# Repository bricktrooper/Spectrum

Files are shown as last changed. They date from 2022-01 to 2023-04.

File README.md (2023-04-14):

# Spectrum

Spectrum is a 10-band stereo graphic equalizer circuit.  It uses active band pass filters in a multiple feedback configuration.  Each band can be individually amplified or attenuated using linear potentiometers.  The circuit requires an external power source of at least 5 V at 250 mA.

## Background

### Graphic Equalizers

A graphic equalizer is a piece of audio equipment that isolates different ranges of frequencies from an audio signal.  These ranges can then be individually amplified (boosted) or attenuated (cut).  The modified signals are mixed back together into a single audio signal which appears at the output.  The resulting signal is the same audio but with each frequency range adjusted with a desired gain.

### Stereo Sound

The most basic form of electrical audio signals is "mono".  This is a single audio signal that plays through all the speakers.  "Stereo" uses two separate audio signals that differ slightly but can be used to give the perception of spatial audio.  Typically, the signals are used to drive separate "left" and "right" speakers.  A graphic equalizer only operates on a single mono signal.  Spectrum effectively uses two identical mono circuits to modify both channels of stereo audio.  The resulting output can be played through stereo headphones.  The circuit must be powered by an external wall adapter or any other 5 V source that can supply approximately 250 mA of current.

## Circuit Design

### Power Supply

Spectrum uses a 5 V power supply that is regulated by an L7805 LDO.  Traditionally, operational amplifiers use a bipolar supply of +VDD and -VDD, with the ground point of the signal being 0 V.  This is not possible with a single supply.  Therefore, Spectrum raises the ground point to a virtual ground of (VDD / 2), or 2.5 V.  The op amps are supplied by 5 V and sink to 0 V (GND).  This provides 2.5 V of signal swing, which is enough for driving headphones to a considerable volume.  To drive large speakers, a separate amplifier should be used.  Capacitive coupling is used to inject an AC audio signal into a 2.5 V bias and decouple the bias at the output headphone jack.

### Preamplifier

The preamplifier's job is to drive the rest of the circuit, effectively isolating the input resistance of the circuit from the audio source.  This is important because headphone jack outputs cannot drive very high impedances.  The preamplifer is also capable of amplifying or attenuating the input signal.  Amplification may be required if the input source is too quiet, while attenuation can be used to reduce distortion in the output signal.  The input to the preamplifier is further isolated using a 1:1 audio transformer.  This prevents the ground of the circuit from creating a ground loop through the audio cable, which creates an undesirable humming noise due to the oscillation of the AC mains voltage.  The preamplifier is implemented as a simple inverting amplifier.  A capacitor is used at the input to strip out any existing DC voltage and the output signal is re-biased at the virtual ground point.  A potentiometer is used in the feedback resistance to amplify or attenuate the signal linearly.

### Band Pass Filters

The core circuit of a graphic equalizer is the band pass filter, which isolates a range of frequencies.  Different resistor and capacitor values are used to achieve different cutoff frequencies over the bass, mid, and treble ranges.  Spectrum uses 10 filters for each audio channel.  The centre frequencies are chosen based on standard octaves:

- 31.5 Hz
- 63 Hz
- 125 Hz
- 250 Hz
- 500 Hz
- 1 kHz
- 2 kHz
- 4 kHz
- 8 kHz
- 16 kHz

These are active filters that used op amps in the multiple-feedback configuration, which allows the cutoff frequency to be changed without affecting the gain of the centre frequency.  The gain of all the filters have been adjusted so that the entire audio range has a flat gain response when the filter outputs are mixed back together.  Each individual filter has a DC gain of 1 V/V, with the exception of 31.5 Hz and 16 kHz, which have a gain of 1.6 V/V.  A quality factor of Q = 1.7 is used for all filters.  The component selection is as follows:

```
-------------------------------------------------------------------------------------------------------------------
| BAND    | ERROR      | C          | R1         | R2         | R3         | f          | Q          | A          |
-------------------------------------------------------------------------------------------------------------------
| 31.5 Hz | 0.816      | 0.33 uF    | 16 K       | 51 K       | 6.2 K      | 31.948 Hz  | 1.689      | 1.594 V/V  |
| 63 Hz   | 0.745      | 0.56 uF    | 7.5 K      | 15 K       | 1.6 K      | 63.902 Hz  | 1.686      | 1.000 V/V  |
| 125 Hz  | 0.709      | 0.22 uF    | 10 K       | 20 K       | 2 K        | 125.302 Hz | 1.732      | 1.000 V/V  |
| 250 Hz  | 0.709      | 0.1 uF     | 11 K       | 22 K       | 2.2 K      | 250.604 Hz | 1.732      | 1.000 V/V  |
| 500 Hz  | 1.204      | 0.1 uF     | 5.6 K      | 11 K       | 1.1 K      | 500.462 Hz | 1.729      | 0.982 V/V  |
| 1 kHz   | 1.328      | 0.18 uF    | 1.5 K      | 3 K        | 0.3 K      | 1.021 kHz  | 1.732      | 1.000 V/V  |
| 2 kHz   | 0.467      | 0.18 uF    | 0.75 K     | 1.5 K      | 0.16 K     | 1.988 kHz  | 1.686      | 1.000 V/V  |
| 4 kHz   | 1.078      | 0.068 uF   | 1 K        | 2 K        | 0.2 K      | 4.054 kHz  | 1.732      | 1.000 V/V  |
| 8 kHz   | 0.812      | 0.033 uF   | 1 K        | 2 K        | 0.22 K     | 8.031 kHz  | 1.665      | 1.000 V/V  |
| 16 kHz  | 0.916      | 0.022 uF   | 0.47 K     | 1.5 K      | 0.18 K     | 16.373 kHz | 1.697      | 1.596 V/V  |
-------------------------------------------------------------------------------------------------------------------
```

### Band Amplifiers

Each band pass filter is followed by an inverting amplifier, which has adjustable gain via a potentiometer in the feedback path.  This allows the user to individually boost or cut different frequency ranges.  At the potentiometer neutral point, the gain of the band amplifier is 0.5 V/V, meaning that each band can be attenuated down to 0 V/V or boosted up to 1 V/V, which is the gain of the band pass filters.  Any further amplification must be provided from the audio source and the preamplifier.  Due to band overlap, the actual realized gain is slightly higher or lower than in theory.  This is a tradeoff between selectivity and gain accuracy.

### Mixer

The mixer is a summing amplifier that re-combines all the band signals back into a single audio signal.  It has a fixed gain of 5 V/V, and the output signal can directly drive low-impedance headphones.  The output signal runs through a large capacitor to cut out the virtual ground DC bias to avoid damaging the headphone speaker coils.  This turns the signal into an AC waveform with a GND as the reference point.

## Schematic

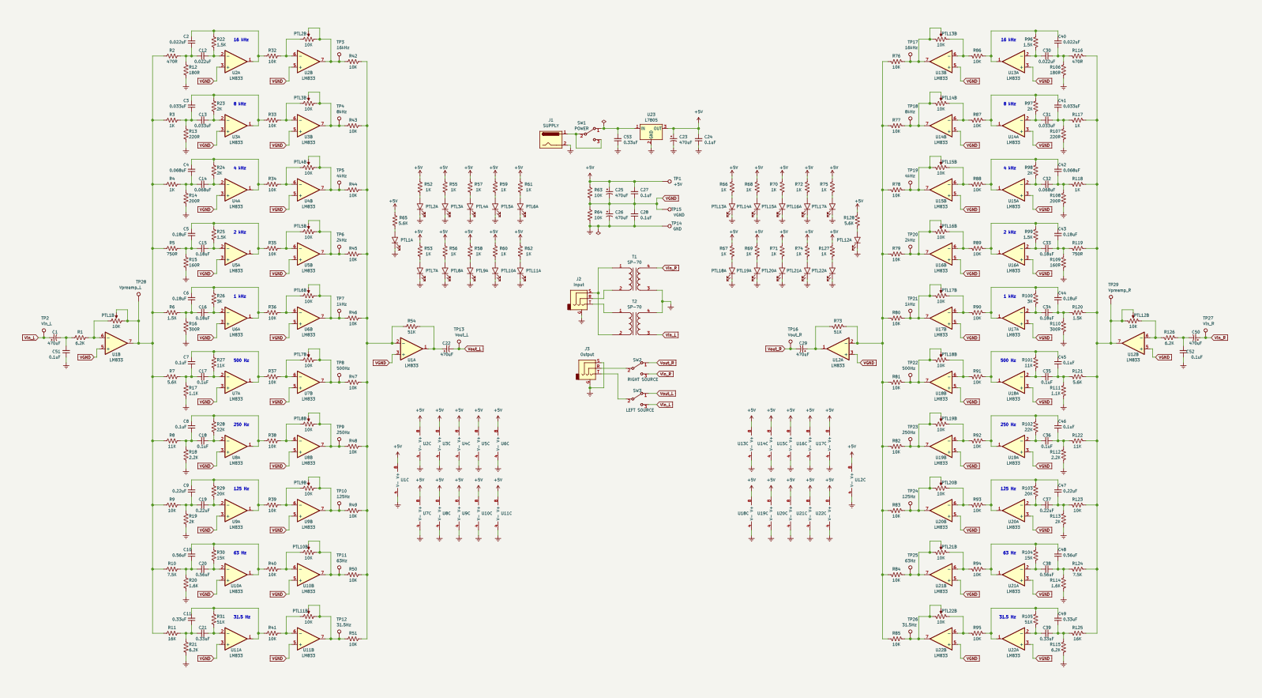
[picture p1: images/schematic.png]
Schematic


## Circuit Board

### Top
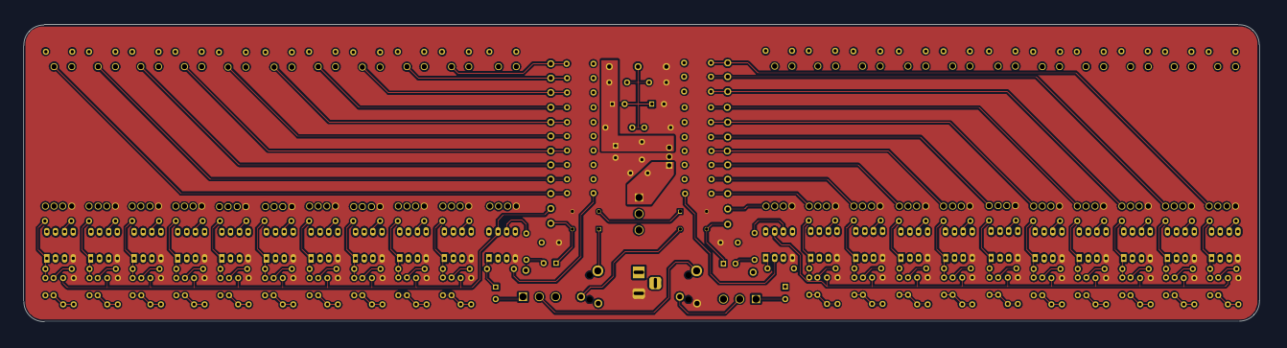
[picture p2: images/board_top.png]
Top


### Bottom
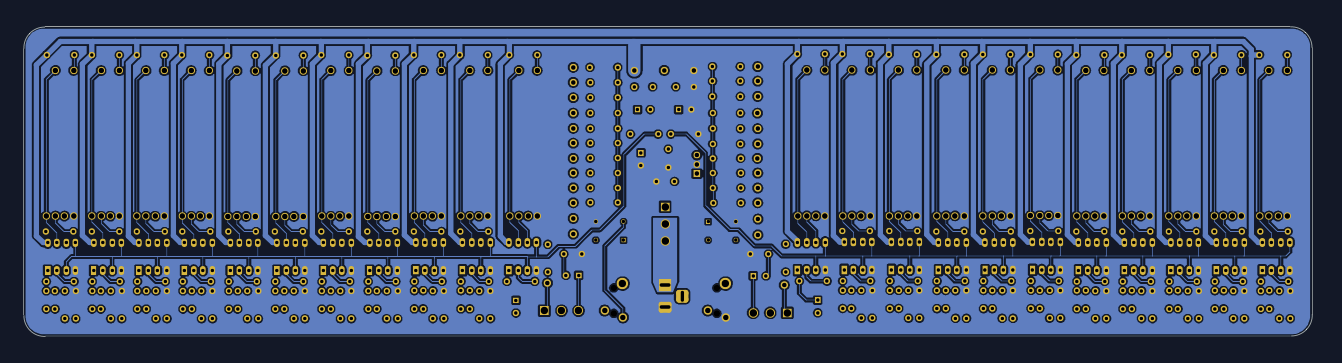
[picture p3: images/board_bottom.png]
Bottom


### Assembled
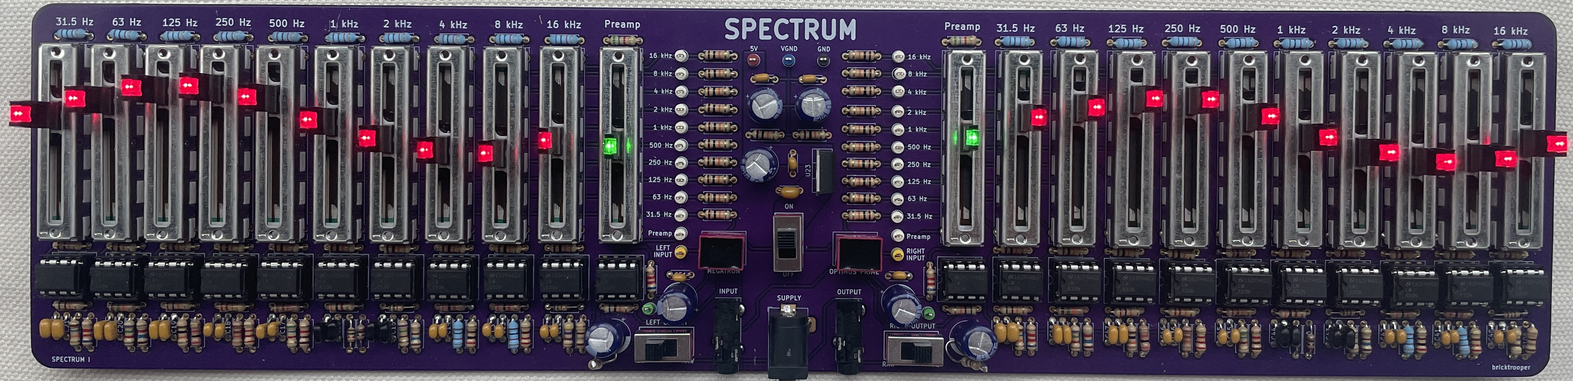
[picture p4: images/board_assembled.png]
Assembled


## Revisions

- A 470R resistor was added to the audio output to mitigate the amplified hissing noise.  The side effect of this is reduced gain from the preamp and increased distortion in the output signal.

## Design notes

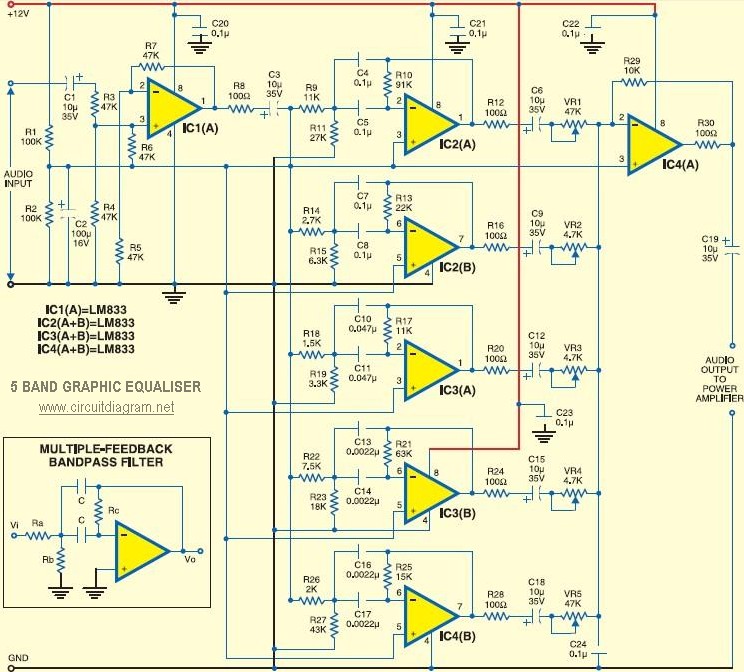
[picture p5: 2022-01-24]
resources/Single Supply Graphic EQ.jpg

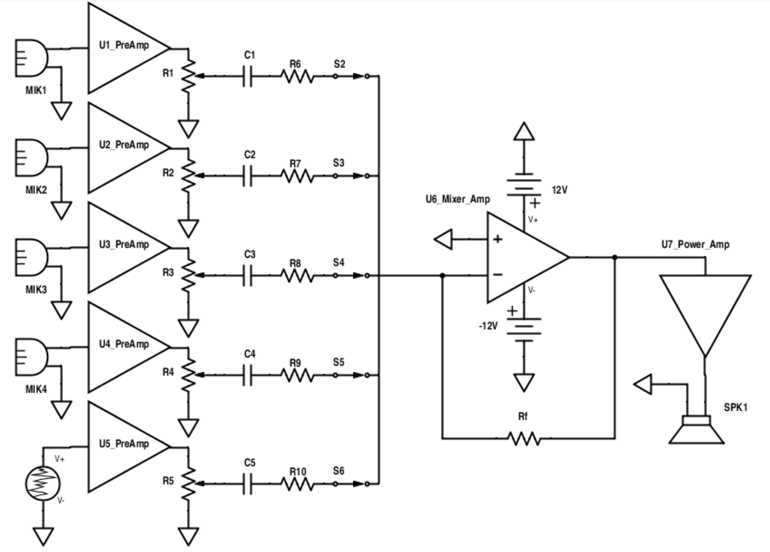
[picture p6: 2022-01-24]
resources/Summing Amplifier Audio Mixer 2.png

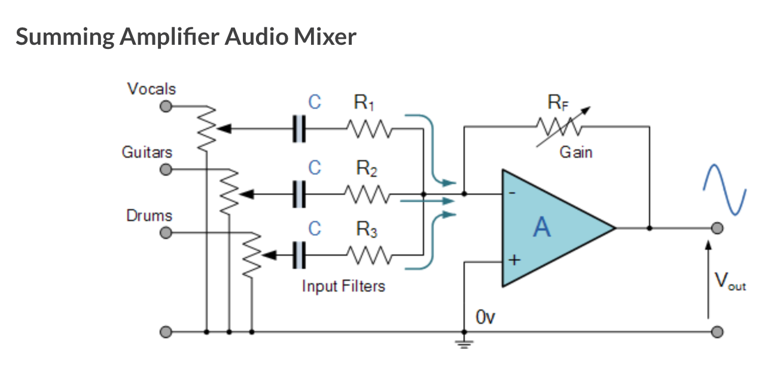
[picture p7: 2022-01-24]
resources/Summing Amplifier Audio Mixer 1.png

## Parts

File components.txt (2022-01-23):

Q = 1.7
A = 1 except for 31.5 Hz and 16 kHz which are 1.6

-------------------------------------------------------------------------------------------------------------------
| BAND    | ERROR      | C          | R1         | R2         | R3         | f          | Q          | A          |
-------------------------------------------------------------------------------------------------------------------
| 31.5 Hz | 0.816      | 0.33 uF    | 16 K       | 51 K       | 6.2 K      | 31.948 Hz  | 1.689      | 1.594 V/V  |
| 63 Hz   | 0.745      | 0.56 uF    | 7.5 K      | 15 K       | 1.6 K      | 63.902 Hz  | 1.686      | 1.000 V/V  |
| 125 Hz  | 0.709      | 0.22 uF    | 10 K       | 20 K       | 2 K        | 125.302 Hz | 1.732      | 1.000 V/V  |
| 250 Hz  | 0.709      | 0.1 uF     | 11 K       | 22 K       | 2.2 K      | 250.604 Hz | 1.732      | 1.000 V/V  |
| 500 Hz  | 1.204      | 0.1 uF     | 5.6 K      | 11 K       | 1.1 K      | 500.462 Hz | 1.729      | 0.982 V/V  |
| 1 kHz   | 1.328      | 0.18 uF    | 1.5 K      | 3 K        | 0.3 K      | 1.021 kHz  | 1.732      | 1.000 V/V  |
| 2 kHz   | 0.467      | 0.18 uF    | 0.75 K     | 1.5 K      | 0.16 K     | 1.988 kHz  | 1.686      | 1.000 V/V  |
| 4 kHz   | 1.078      | 0.068 uF   | 1 K        | 2 K        | 0.2 K      | 4.054 kHz  | 1.732      | 1.000 V/V  |
| 8 kHz   | 0.812      | 0.033 uF   | 1 K        | 2 K        | 0.22 K     | 8.031 kHz  | 1.665      | 1.000 V/V  |
| 16 kHz  | 0.916      | 0.022 uF   | 0.47 K     | 1.5 K      | 0.18 K     | 16.373 kHz | 1.697      | 1.596 V/V  |
-------------------------------------------------------------------------------------------------------------------

Blocking capacitors will be 10 uF each with a companion resistor of 100 R.
The POT will be 10 K (at least 10 times the size of the resistor).

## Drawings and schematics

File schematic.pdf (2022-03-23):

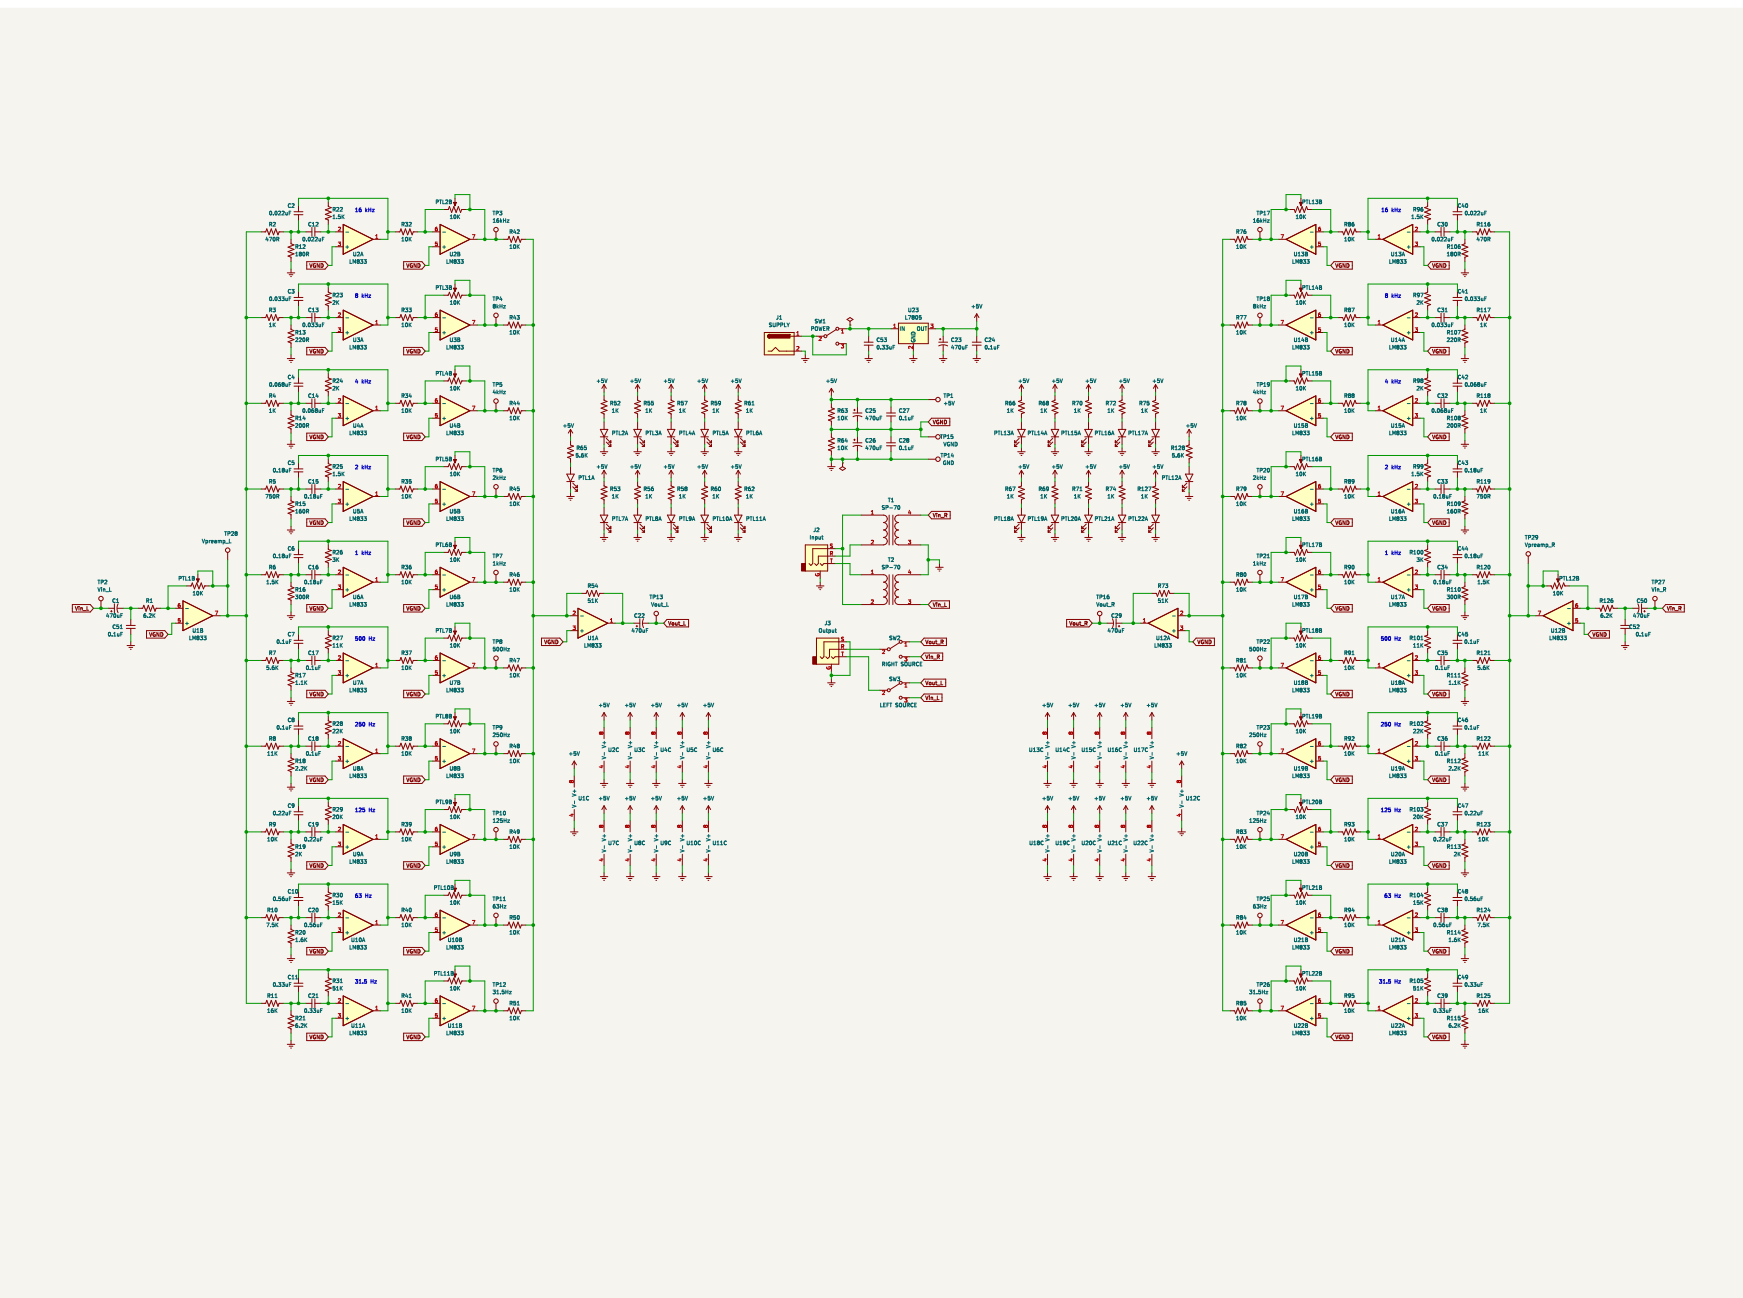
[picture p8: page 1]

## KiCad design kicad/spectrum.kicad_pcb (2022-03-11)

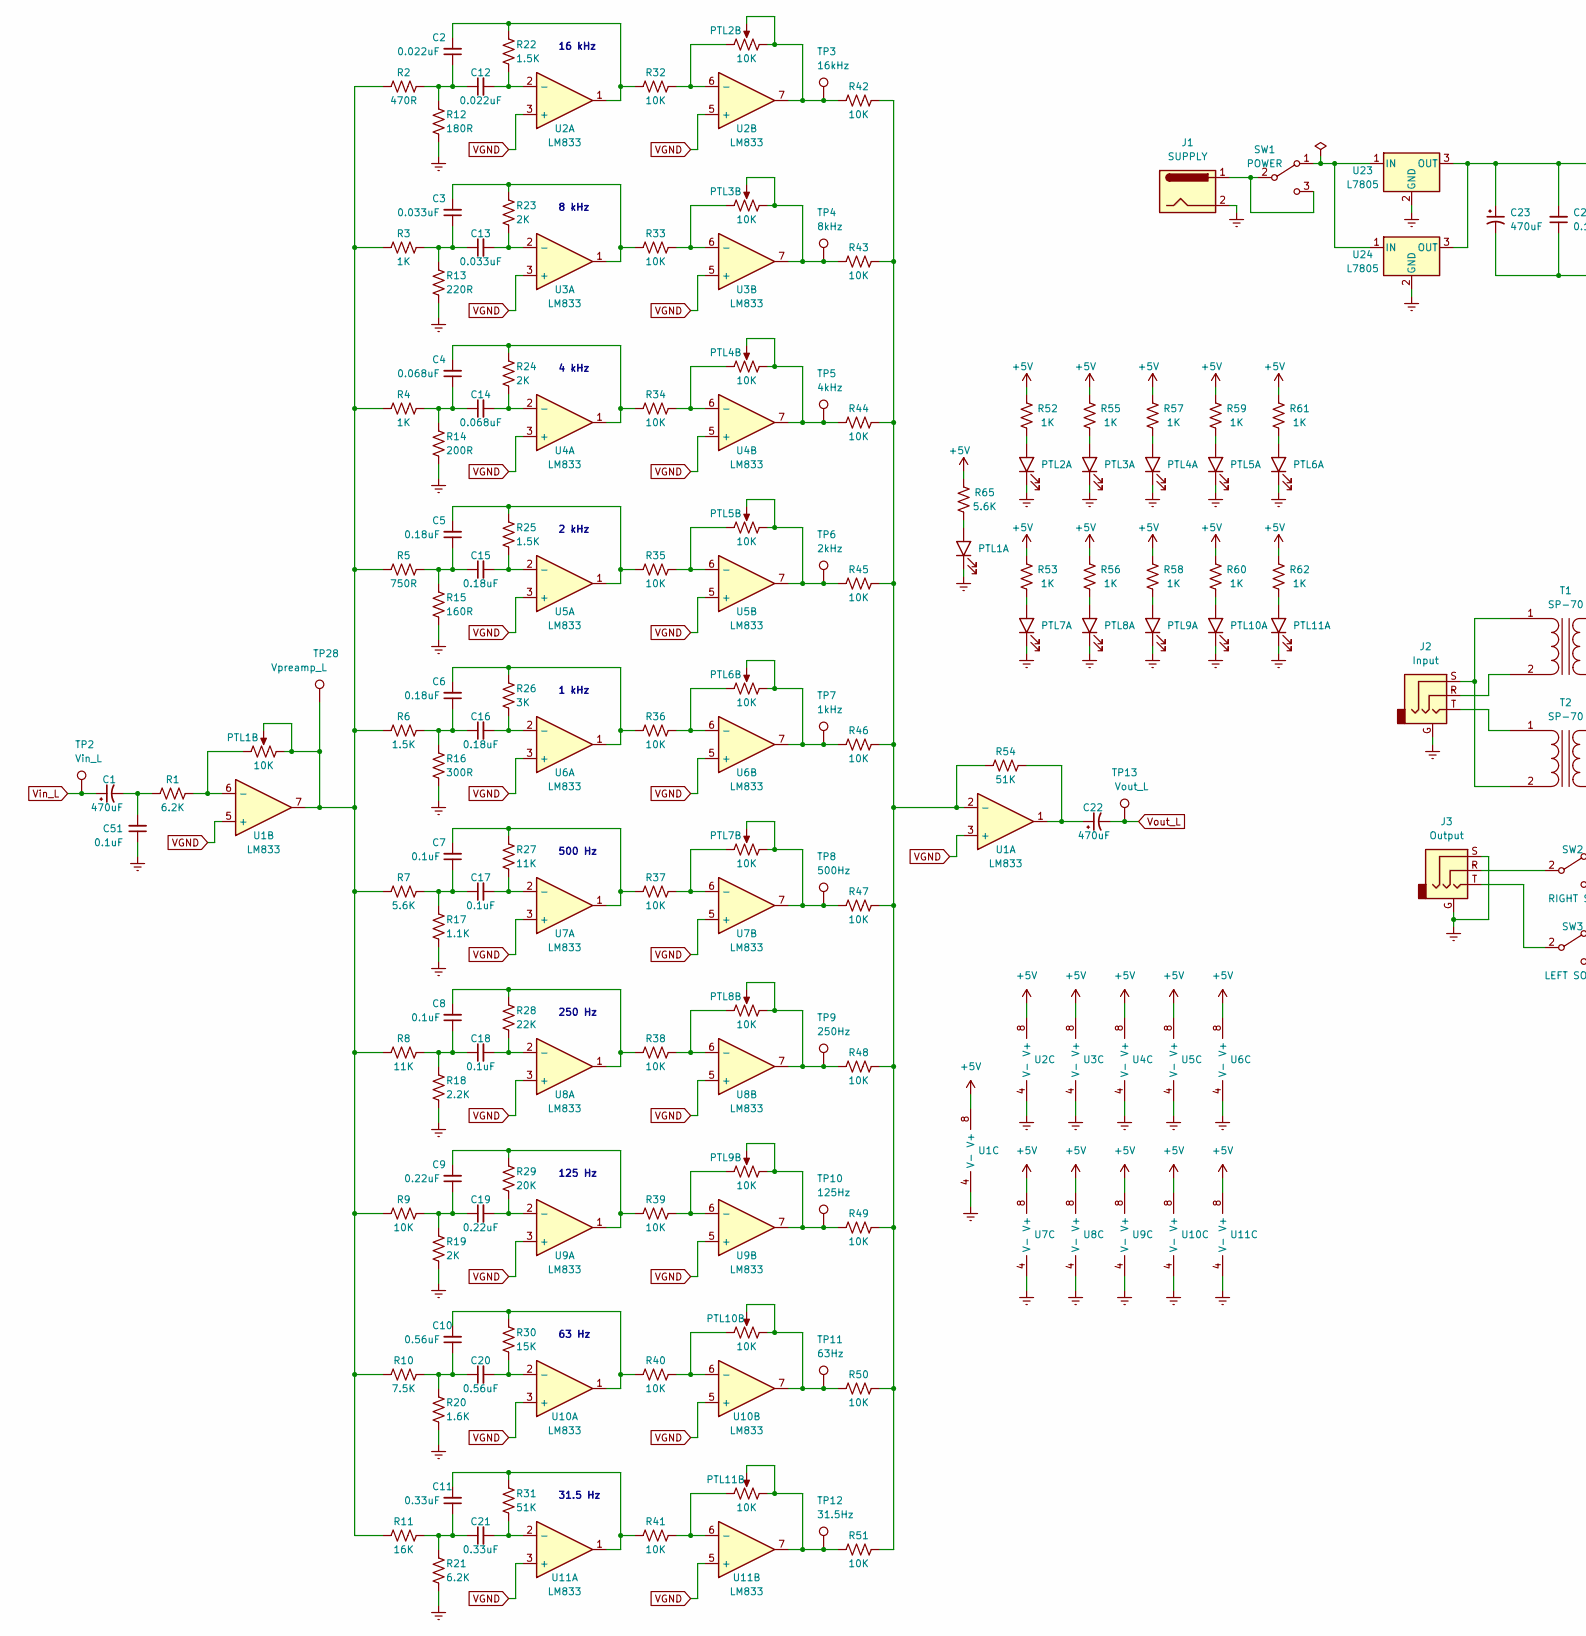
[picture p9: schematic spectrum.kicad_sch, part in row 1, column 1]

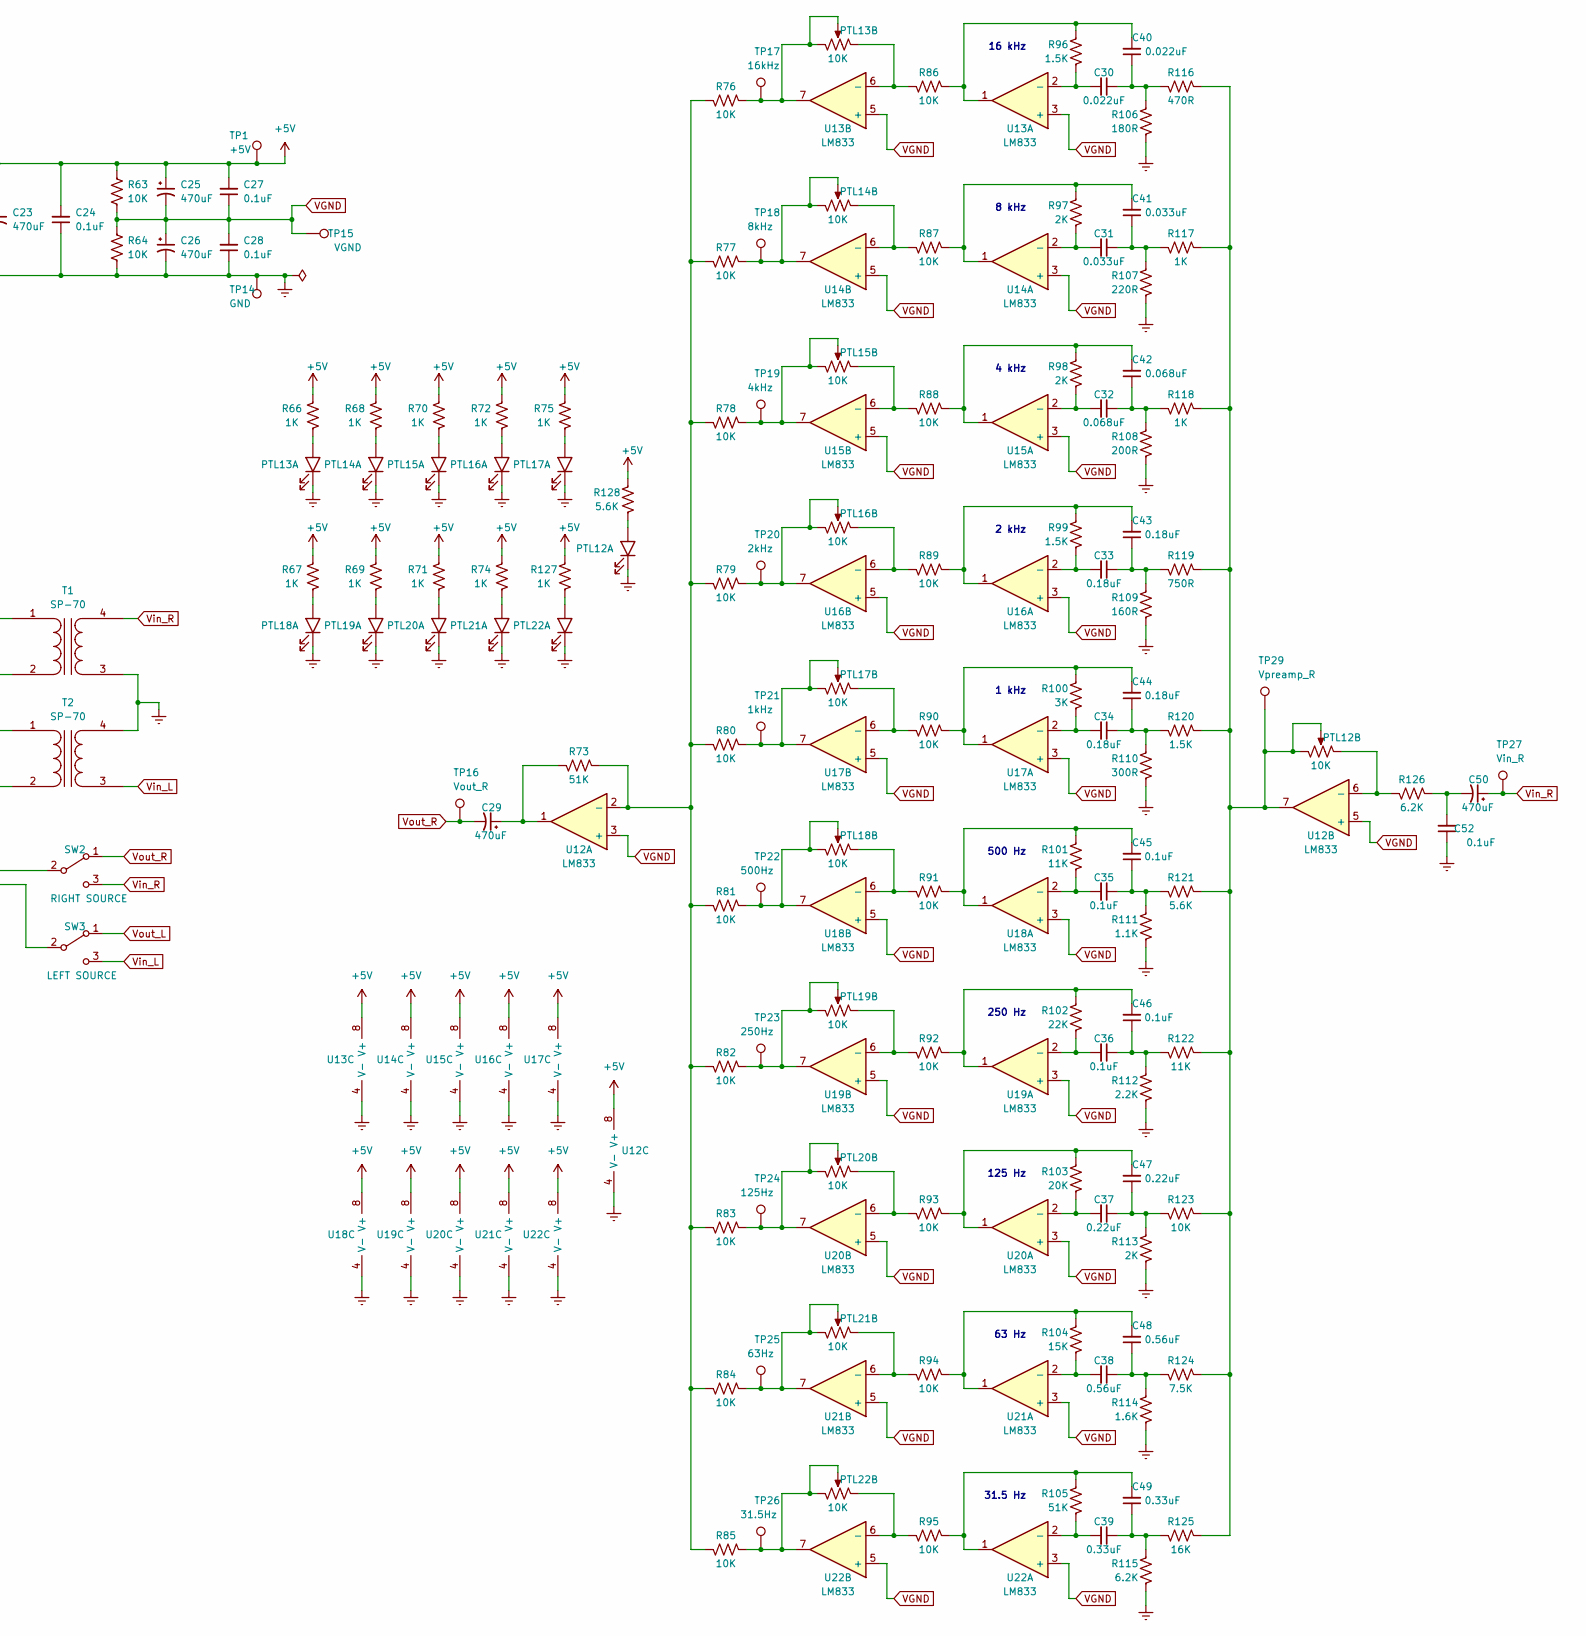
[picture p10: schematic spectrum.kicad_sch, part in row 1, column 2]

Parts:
C1, C22, C23, C25, C26, C29, C50: 470uF; CP_Radial_D8.0mm_P3.50mm
C2, C12, C30, C40: 0.022uF; C_Disc_D4.3mm_W1.9mm_P5.00mm
C3, C13, C31, C41: 0.033uF; C_Disc_D4.3mm_W1.9mm_P5.00mm
C4, C14, C32, C42: 0.068uF; C_Disc_D4.3mm_W1.9mm_P5.00mm
C5, C6, C15, C16, C33, C34, C43, C44: 0.18uF; C_Disc_D4.3mm_W1.9mm_P5.00mm
C7, C8, C17, C18, C24, C27, C28, C35, C36, C45, C46, C51, C52: 0.1uF; C_Disc_D4.3mm_W1.9mm_P5.00mm
C9, C19, C37, C47: 0.22uF; C_Disc_D4.3mm_W1.9mm_P5.00mm
C10, C20, C38, C48: 0.56uF; C_Disc_D4.3mm_W1.9mm_P5.00mm
C11, C21, C39, C49: 0.33uF; C_Disc_D4.3mm_W1.9mm_P5.00mm
J1: SUPPLY; BarrelJack_Horizontal
J2: Input; STX35013N
J3: Output; STX35013N
PTL1, PTL2, PTL3, PTL4, PTL5, PTL6, PTL7, PTL8, PTL9, PTL10, PTL11, PTL12, PTL13, PTL14, PTL15, PTL16, PTL17, PTL18, PTL19, PTL20, PTL21, PTL22: 10K; PTL30
R1, R21, R115, R126: 6.2K; R_Axial_DIN0207_L6.3mm_D2.5mm_P7.62mm_Horizontal
R2, R116: 470R; R_Axial_DIN0207_L6.3mm_D2.5mm_P7.62mm_Horizontal
R3, R4, R52, R53, R55, R56, R57, R58, R59, R60, R61, R62, R66, R67, R68, R69, R70, R71, R72, R74, R75, R117, R118, R127: 1K; R_Axial_DIN0207_L6.3mm_D2.5mm_P7.62mm_Horizontal
R5, R119: 750R; R_Axial_DIN0207_L6.3mm_D2.5mm_P7.62mm_Horizontal
R6, R22, R25, R96, R99, R120: 1.5K; R_Axial_DIN0207_L6.3mm_D2.5mm_P7.62mm_Horizontal
R7, R65, R121, R128: 5.6K; R_Axial_DIN0207_L6.3mm_D2.5mm_P7.62mm_Horizontal
R8, R27, R101, R122: 11K; R_Axial_DIN0207_L6.3mm_D2.5mm_P7.62mm_Horizontal
R9, R32, R33, R34, R35, R36, R37, R38, R39, R40, R41, R42, R43, R44, R45, R46, R47, R48, R49, R50, R51, R63, R64, R76, R77, R78, R79, R80, R81, R82, R83, R84, R85, R86, R87, R88, R89, R90, R91, R92, R93, R94, R95, R123: 10K; R_Axial_DIN0207_L6.3mm_D2.5mm_P7.62mm_Horizontal
R10, R124: 7.5K; R_Axial_DIN0207_L6.3mm_D2.5mm_P7.62mm_Horizontal
R11, R125: 16K; R_Axial_DIN0207_L6.3mm_D2.5mm_P7.62mm_Horizontal
R12, R106: 180R; R_Axial_DIN0207_L6.3mm_D2.5mm_P7.62mm_Horizontal
R13, R107: 220R; R_Axial_DIN0207_L6.3mm_D2.5mm_P7.62mm_Horizontal
R14, R108: 200R; R_Axial_DIN0207_L6.3mm_D2.5mm_P7.62mm_Horizontal
R15, R109: 160R; R_Axial_DIN0207_L6.3mm_D2.5mm_P7.62mm_Horizontal
R16, R110: 300R; R_Axial_DIN0207_L6.3mm_D2.5mm_P7.62mm_Horizontal
R17, R111: 1.1K; R_Axial_DIN0207_L6.3mm_D2.5mm_P7.62mm_Horizontal
R18, R112: 2.2K; R_Axial_DIN0207_L6.3mm_D2.5mm_P7.62mm_Horizontal
R19, R23, R24, R97, R98, R113: 2K; R_Axial_DIN0207_L6.3mm_D2.5mm_P7.62mm_Horizontal
R20, R114: 1.6K; R_Axial_DIN0207_L6.3mm_D2.5mm_P7.62mm_Horizontal
R26, R100: 3K; R_Axial_DIN0207_L6.3mm_D2.5mm_P7.62mm_Horizontal
R28, R102: 22K; R_Axial_DIN0207_L6.3mm_D2.5mm_P7.62mm_Horizontal
R29, R103: 20K; R_Axial_DIN0207_L6.3mm_D2.5mm_P7.62mm_Horizontal
R30, R104: 15K; R_Axial_DIN0207_L6.3mm_D2.5mm_P7.62mm_Horizontal
R31, R54, R73, R105: 51K; R_Axial_DIN0207_L6.3mm_D2.5mm_P7.62mm_Horizontal
SW1: POWER; SW_1101M2S3CQE2
SW2: RIGHT SOURCE; SW_1101M2S3CQE2
SW3: LEFT SOURCE; SW_1101M2S3CQE2
T1, T2: SP-70; SP70
TP1: +5V; TestPoint_Keystone_5000-5004_Miniature
TP2: Vin_L; TestPoint_Keystone_5000-5004_Miniature
TP3, TP17: 16kHz; TestPoint_Keystone_5000-5004_Miniature
TP4, TP18: 8kHz; TestPoint_Keystone_5000-5004_Miniature
TP5, TP19: 4kHz; TestPoint_Keystone_5000-5004_Miniature
TP6, TP20: 2kHz; TestPoint_Keystone_5000-5004_Miniature
TP7, TP21: 1kHz; TestPoint_Keystone_5000-5004_Miniature
TP8, TP22: 500Hz; TestPoint_Keystone_5000-5004_Miniature
TP9, TP23: 250Hz; TestPoint_Keystone_5000-5004_Miniature
TP10, TP24: 125Hz; TestPoint_Keystone_5000-5004_Miniature
TP11, TP25: 63Hz; TestPoint_Keystone_5000-5004_Miniature
TP12, TP26: 31.5Hz; TestPoint_Keystone_5000-5004_Miniature
TP13: Vout_L; TestPoint_Keystone_5000-5004_Miniature
TP14: GND; TestPoint_Keystone_5000-5004_Miniature
TP15: VGND; TestPoint_Keystone_5000-5004_Miniature
TP16: Vout_R; TestPoint_Keystone_5000-5004_Miniature
TP27: Vin_R; TestPoint_Keystone_5000-5004_Miniature
TP28: Vpreamp_L; TestPoint_Keystone_5000-5004_Miniature
TP29: Vpreamp_R; TestPoint_Keystone_5000-5004_Miniature
U1, U2, U3, U4, U5, U6, U7, U8, U9, U10, U11, U12, U13, U14, U15, U16, U17, U18, U19, U20, U21, U22: LM833; DIP-8_W7.62mm_Socket_LongPads
U23, U24: L7805; TO-220-3_Vertical

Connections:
+5V: C23.1, C24.2, C25.1, C27.2, R52.1, R53.1, R55.1, R56.1, R57.1, R58.1, R59.1, R60.1, R61.1, R62.1, R63.1, R65.1, R66.1, R67.1, R68.1, R69.1, R70.1, R71.1, R72.1, R74.1, R75.1, R127.1, R128.1, TP1.1, U1.8 (V+), U2.8 (V+), U3.8 (V+), U4.8 (V+), U5.8 (V+), U6.8 (V+), U7.8 (V+), U8.8 (V+), U9.8 (V+), U10.8 (V+), U11.8 (V+), U12.8 (V+), U13.8 (V+), U14.8 (V+), U15.8 (V+), U16.8 (V+), U17.8 (V+), U18.8 (V+), U19.8 (V+), U20.8 (V+), U21.8 (V+), U22.8 (V+), U23.3 (OUT), U24.3 (OUT)
GNDREF: C23.2, C24.1, C26.2, C28.1, C51.1, C52.1, J1.2, J2.G, J3.G, J3.S, PTL1.5 (E), PTL2.5 (E), PTL3.5 (E), PTL4.5 (E), PTL5.5 (E), PTL6.5 (E), PTL7.5 (E), PTL8.5 (E), PTL9.5 (E), PTL10.5 (E), PTL11.5 (E), PTL12.5 (E), PTL13.5 (E), PTL14.5 (E), PTL15.5 (E), PTL16.5 (E), PTL17.5 (E), PTL18.5 (E), PTL19.5 (E), PTL20.5 (E), PTL21.5 (E), PTL22.5 (E), R12.2, R13.2, R14.2, R15.2, R16.2, R17.2, R18.2, R19.2, R20.2, R21.2, R64.2, R106.2, R107.2, R108.2, R109.2, R110.2, R111.2, R112.2, R113.2, R114.2, R115.2, T1.3 (SA), T2.4 (SB), TP14.1, U1.4 (V-), U2.4 (V-), U3.4 (V-), U4.4 (V-), U5.4 (V-), U6.4 (V-), U7.4 (V-), U8.4 (V-), U9.4 (V-), U10.4 (V-), U11.4 (V-), U12.4 (V-), U13.4 (V-), U14.4 (V-), U15.4 (V-), U16.4 (V-), U17.4 (V-), U18.4 (V-), U19.4 (V-), U20.4 (V-), U21.4 (V-), U22.4 (V-), U23.2 (GND), U24.2 (GND)
unnamed: C1.2, C51.2, R1.2
unnamed: C2.2, R22.1, R32.2, U2.1
unnamed: C3.2, R23.1, R33.2, U3.1
unnamed: C4.2, R24.1, R34.2, U4.1
unnamed: C5.2, R25.1, R35.2, U5.1
unnamed: C6.2, R26.1, R36.2, U6.1
unnamed: C7.2, R27.1, R37.2, U7.1
unnamed: C8.2, R28.1, R38.2, U8.1
unnamed: C9.2, R29.1, R39.2, U9.1
unnamed: C10.1, C20.1, R10.1, R20.1
unnamed: C10.2, R30.1, R40.2, U10.1
unnamed: C11.1, C21.1, R11.1, R21.1
unnamed: C11.2, R31.1, R41.2, U11.1
unnamed: C2.1, C12.1, R2.1, R12.1
unnamed: C12.2, R22.2, U2.2 (-)
unnamed: C3.1, C13.1, R3.1, R13.1
unnamed: C13.2, R23.2, U3.2 (-)
unnamed: C4.1, C14.1, R4.1, R14.1
unnamed: C14.2, R24.2, U4.2 (-)
unnamed: C5.1, C15.1, R5.1, R15.1
unnamed: C15.2, R25.2, U5.2 (-)
unnamed: C6.1, C16.1, R6.1, R16.1
unnamed: C16.2, R26.2, U6.2 (-)
unnamed: C7.1, C17.1, R7.1, R17.1
unnamed: C17.2, R27.2, U7.2 (-)
unnamed: C8.1, C18.1, R8.1, R18.1
unnamed: C18.2, R28.2, U8.2 (-)
unnamed: C9.1, C19.1, R9.1, R19.1
unnamed: C19.2, R29.2, U9.2 (-)
unnamed: C20.2, R30.2, U10.2 (-)
unnamed: C21.2, R31.2, U11.2 (-)
unnamed: C22.1, R54.1, U1.1
unnamed: C29.1, R73.1, U12.1
unnamed: C30.1, C40.1, R106.1, R116.1
unnamed: C30.2, R96.2, U13.2 (-)
unnamed: C31.1, C41.1, R107.1, R117.1
unnamed: C31.2, R97.2, U14.2 (-)
unnamed: C32.1, C42.1, R108.1, R118.1
unnamed: C32.2, R98.2, U15.2 (-)
unnamed: C33.1, C43.1, R109.1, R119.1
unnamed: C33.2, R99.2, U16.2 (-)
unnamed: C34.1, C44.1, R110.1, R120.1
unnamed: C34.2, R100.2, U17.2 (-)
unnamed: C35.1, C45.1, R111.1, R121.1
unnamed: C35.2, R101.2, U18.2 (-)
unnamed: C36.1, C46.1, R112.1, R122.1
unnamed: C36.2, R102.2, U19.2 (-)
unnamed: C37.1, C47.1, R113.1, R123.1
unnamed: C37.2, R103.2, U20.2 (-)
unnamed: C38.1, C48.1, R114.1, R124.1
unnamed: C38.2, R104.2, U21.2 (-)
unnamed: C39.1, C49.1, R115.1, R125.1
unnamed: C39.2, R105.2, U22.2 (-)
unnamed: C40.2, R86.2, R96.1, U13.1
unnamed: C41.2, R87.2, R97.1, U14.1
unnamed: C42.2, R88.2, R98.1, U15.1
unnamed: C43.2, R89.2, R99.1, U16.1
unnamed: C44.2, R90.2, R100.1, U17.1
unnamed: C45.2, R91.2, R101.1, U18.1
unnamed: C46.2, R92.2, R102.1, U19.1
unnamed: C47.2, R93.2, R103.1, U20.1
unnamed: C48.2, R94.2, R104.1, U21.1
unnamed: C49.2, R95.2, R105.1, U22.1
unnamed: C50.2, C52.2, R126.2
unnamed: J1.1, SW1.2 (B), SW1.3 (C)
unnamed: J2.R, T1.2 (AB)
unnamed: J2.S, T1.1 (AA), T2.2 (AB)
unnamed: J2.T, T2.1 (AA)
unnamed: J3.R, SW2.2 (B)
unnamed: J3.T, SW3.2 (B)
unnamed: PTL1.1, R1.1, U1.6 (-)
unnamed: PTL1.2, PTL1.3, R2.2, R3.2, R4.2, R5.2, R6.2, R7.2, R8.2, R9.2, R10.2, R11.2, TP28.1, U1.7
unnamed: PTL1.4 (B), R65.2
unnamed: PTL2.1, R32.1, U2.6 (-)
unnamed: PTL2.2, PTL2.3, R42.2, TP3.1, U2.7
unnamed: PTL2.4 (B), R52.2
unnamed: PTL3.1, R33.1, U3.6 (-)
unnamed: PTL3.2, PTL3.3, R43.2, TP4.1, U3.7
unnamed: PTL3.4 (B), R55.2
unnamed: PTL4.1, R34.1, U4.6 (-)
unnamed: PTL4.2, PTL4.3, R44.2, TP5.1, U4.7
unnamed: PTL4.4 (B), R57.2
unnamed: PTL5.1, R35.1, U5.6 (-)
unnamed: PTL5.2, PTL5.3, R45.2, TP6.1, U5.7
unnamed: PTL5.4 (B), R59.2
unnamed: PTL6.1, R36.1, U6.6 (-)
unnamed: PTL6.2, PTL6.3, R46.2, TP7.1, U6.7
unnamed: PTL6.4 (B), R61.2
unnamed: PTL7.1, R37.1, U7.6 (-)
unnamed: PTL7.2, PTL7.3, R47.2, TP8.1, U7.7
unnamed: PTL7.4 (B), R53.2
unnamed: PTL8.1, R38.1, U8.6 (-)
unnamed: PTL8.2, PTL8.3, R48.2, TP9.1, U8.7
unnamed: PTL8.4 (B), R56.2
unnamed: PTL9.1, R39.1, U9.6 (-)
unnamed: PTL9.2, PTL9.3, R49.2, TP10.1, U9.7
unnamed: PTL9.4 (B), R58.2
unnamed: PTL10.1, R40.1, U10.6 (-)
unnamed: PTL10.2, PTL10.3, R50.2, TP11.1, U10.7
unnamed: PTL10.4 (B), R60.2
unnamed: PTL11.1, R41.1, U11.6 (-)
unnamed: PTL11.2, PTL11.3, R51.2, TP12.1, U11.7
unnamed: PTL11.4 (B), R62.2
unnamed: PTL12.1, R126.1, U12.6 (-)
unnamed: PTL12.2, PTL12.3, R116.2, R117.2, R118.2, R119.2, R120.2, R121.2, R122.2, R123.2, R124.2, R125.2, TP29.1, U12.7
unnamed: PTL12.4 (B), R128.2
unnamed: PTL13.1, R86.1, U13.6 (-)
unnamed: PTL13.2, PTL13.3, R76.2, TP17.1, U13.7
unnamed: PTL13.4 (B), R66.2
unnamed: PTL14.1, R87.1, U14.6 (-)
unnamed: PTL14.2, PTL14.3, R77.2, TP18.1, U14.7
unnamed: PTL14.4 (B), R68.2
unnamed: PTL15.1, R88.1, U15.6 (-)
unnamed: PTL15.2, PTL15.3, R78.2, TP19.1, U15.7
unnamed: PTL15.4 (B), R70.2
unnamed: PTL16.1, R89.1, U16.6 (-)
unnamed: PTL16.2, PTL16.3, R79.2, TP20.1, U16.7
unnamed: PTL16.4 (B), R72.2
unnamed: PTL17.1, R90.1, U17.6 (-)
unnamed: PTL17.2, PTL17.3, R80.2, TP21.1, U17.7
unnamed: PTL17.4 (B), R75.2
unnamed: PTL18.1, R91.1, U18.6 (-)
unnamed: PTL18.2, PTL18.3, R81.2, TP22.1, U18.7
unnamed: PTL18.4 (B), R67.2
unnamed: PTL19.1, R92.1, U19.6 (-)
unnamed: PTL19.2, PTL19.3, R82.2, TP23.1, U19.7
unnamed: PTL19.4 (B), R69.2
unnamed: PTL20.1, R93.1, U20.6 (-)
unnamed: PTL20.2, PTL20.3, R83.2, TP24.1, U20.7
unnamed: PTL20.4 (B), R71.2
unnamed: PTL21.1, R94.1, U21.6 (-)
unnamed: PTL21.2, PTL21.3, R84.2, TP25.1, U21.7
unnamed: PTL21.4 (B), R74.2
unnamed: PTL22.1, R95.1, U22.6 (-)
unnamed: PTL22.2, PTL22.3, R85.2, TP26.1, U22.7
unnamed: PTL22.4 (B), R127.2
unnamed: R42.1, R43.1, R44.1, R45.1, R46.1, R47.1, R48.1, R49.1, R50.1, R51.1, R54.2, U1.2 (-)
unnamed: R73.2, R76.1, R77.1, R78.1, R79.1, R80.1, R81.1, R82.1, R83.1, R84.1, R85.1, U12.2 (-)
unnamed: SW1.1 (A), U23.1 (IN), U24.1 (IN)
VGND: C25.2, C26.1, C27.1, C28.2, R63.2, R64.1, TP15.1, U1.3 (+), U1.5 (+), U2.3 (+), U2.5 (+), U3.3 (+), U3.5 (+), U4.3 (+), U4.5 (+), U5.3 (+), U5.5 (+), U6.3 (+), U6.5 (+), U7.3 (+), U7.5 (+), U8.3 (+), U8.5 (+), U9.3 (+), U9.5 (+), U10.3 (+), U10.5 (+), U11.3 (+), U11.5 (+), U12.3 (+), U12.5 (+), U13.3 (+), U13.5 (+), U14.3 (+), U14.5 (+), U15.3 (+), U15.5 (+), U16.3 (+), U16.5 (+), U17.3 (+), U17.5 (+), U18.3 (+), U18.5 (+), U19.3 (+), U19.5 (+), U20.3 (+), U20.5 (+), U21.3 (+), U21.5 (+), U22.3 (+), U22.5 (+)
Vin_L: C1.1, SW3.3 (C), T2.3 (SA), TP2.1
Vin_R: C50.1, SW2.3 (C), T1.4 (SB), TP27.1
Vout_L: C22.2, SW3.1 (A), TP13.1
Vout_R: C29.2, SW2.1 (A), TP16.1

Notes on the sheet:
16 kHz
125 Hz
250 Hz
500 Hz
4 kHz
8 kHz
63 Hz
31.5 Hz
1 kHz
2 kHz

Board: 2 copper layers, 263 parts (0 on the bottom side), 146 nets, no tracks yet.

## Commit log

2022-01-17 Script for calculating optimal resistor and capacitor values
2022-01-17 Print out actual Q, f, and A
2022-01-23 Create BPF in KiCad
    [spectrum.kicad_pcb, spectrum.kicad_sch]
2022-01-23 Choose resistors and capacitors for band pass filters
2022-01-23 Modify script to match standard resistor and capacitor charts
2022-01-29 Fix swapped BPF input terminals to be inverting
    [spectrum.kicad_sch]
2022-01-29 Move volume POT to preamp
    [spectrum.kicad_sch]
2022-01-30 Band pass filter array
    [spectrum.kicad_sch]
2022-01-30 Left and right stereo filters
    [spectrum.kicad_sch]
2022-01-30 Footprint and symbol for Bourns PTL POT with LEDs
    [spectrum.kicad_sch]
2022-01-30 30 mm Bourns PTL footprint
    [spectrum.kicad_sch]
2022-01-30 Test points
    [spectrum.kicad_sch]
2022-01-31 Switch to USB-A
    [spectrum.kicad_sch]
2022-02-01 Resistor datasheet
2022-02-12 Increase preamp input resistor to 1K
    [spectrum.kicad_sch]
2022-02-13 Fix POT LEDs and use barrel jack for power
    [spectrum.kicad_sch]
2022-02-13 Organize parts
    [spectrum.kicad_pcb]
2022-02-13 Fix POT footprint and pins
    [spectrum.kicad_pcb]
2022-02-13 Filter array component layout
    [spectrum.kicad_pcb, spectrum.kicad_sch]
2022-02-13 Fix bypass routes
    [spectrum.kicad_pcb, spectrum.kicad_sch]
2022-02-14 More component layout
    [spectrum.kicad_pcb, spectrum.kicad_sch]
2022-02-28 Isolation transformer and resistor tweaks
    - Audio isolation transformer to fix ground loop hum.
    - Changed preamp Ri and mixer Rf to work compensate
    for transfomer effects.
    [spectrum.kicad_sch]
2022-03-11 Finish component layout and add extra 7805
    - Extra 7805 needed for heat dissipation
    [spectrum.kicad_pcb, spectrum.kicad_sch]
2022-03-14 Route PCB
2022-03-14 Rounded board edges
2022-03-15 Clean up board traces and use single L7805
    [spectrum.kicad_sch]
2022-03-16 Finalize PCB
2022-03-16 Generate Gerbers
    [spectrum-B_Cu.gbr, spectrum-B_Mask.gbr, spectrum-B_Silkscreen.gbr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]
2022-03-22 Add GLB circuit paper from TI
2022-03-23 Add schematic PDF
2022-03-28 Fix trace that was close to pad
2022-03-28 Thermal reliefs for bottom copper
    For easier hand soldering (I learned this the hard way).
2022-04-17 Add output resistor to cut out noise
    [spectrum.kicad_sch]
2022-04-17 Add picture of final assembled board
2022-08-14 Print bandwidth in script
